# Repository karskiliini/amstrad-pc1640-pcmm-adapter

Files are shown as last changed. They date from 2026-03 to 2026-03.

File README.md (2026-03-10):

# amstrad-pc1640-pcmm-adapter

Video adapter for connecting an Amstrad PC1640 to an Amstrad PC-MM monochrome monitor.

The PC1640 and PC-MM were never designed to work together — the PC-MM was built for the PC1512. This project documents the signal incompatibilities and presents four adapter designs to bridge them.

## The Problem

| Issue | PC1640 output | PC-MM expects |
|---|---|---|
| Connector | DE-9 (9-pin D-sub) | 8-pin DIN |
| Signal polarity | Normal (active-high TTL) | Inverted (active-low TTL) |
| Sync | Separate H-Sync + V-Sync | Composite Sync (combined) |
| Frequency | 21.85 kHz (EGA) / 15.7 kHz (CGA) | 15.75 kHz only |
| Power (14-pin DIN) | Same pinout | Same pinout — **compatible** |

**Solutions:** Run PC1640 in CGA mode (SW8 = OFF) for simplest adapter, or keep EGA mode (SW8 = ON) with additional signal conversion. See options below.

## Documentation

- **[Signal Analysis](docs/signal-analysis.md)** — Full pinouts, signal levels, frequency specs, and compatibility breakdown for both devices

## Adapter Options

### CGA mode (SW8 = OFF) — simpler adapter

| | Option A | Option B | Option C |
|---|---|---|---|
| **Approach** | External adapter | Monitor internal bypass | Passive test cable |
| **ICs needed** | 2 (74HC04 + 74HC86) | 1 (74HC86) | 0 |
| **Monitor mod** | No | Yes | No |
| **Image quality** | Correct | Correct | Inverted (negative) |
| **Cost** | ~15–20€ | ~12–15€ | ~5€ |
| **Difficulty** | Easy | Medium | Very easy |
| **Reversible** | Fully | Partially | Fully |
| **Recommended** | **Yes** | For advanced users | Testing only |

### [Option A: External Adapter](docs/option-a-external-adapter.md) (recommended for CGA mode)

Two ICs on a small PCB handle everything:
- **74HC04** inverts R, G, B, I, and C-Sync to match PC-MM's active-low input
- **74HC86** combines H-Sync + V-Sync into Composite Sync via XOR

No monitor modification needed. Fully reversible.

### [Option B: Monitor Internal Bypass](docs/option-b-monitor-bypass.md)

Bypass the PC-MM's internal TC74HC04 inverter, allowing standard TTL signals to pass through directly. The adapter only needs sync combining (one 74HC86). Smaller and simpler adapter PCB, but requires opening the CRT monitor.

### [Option C: Passive Test Cable](docs/option-c-passive-test.md)

Quick-and-dirty test with just two resistors and direct wiring. Image will be inverted (negative), but confirms that the signal path and frequency are compatible before committing to a PCB design.

---

### EGA mode (SW8 = ON) — preserves full EGA capability

### [Option D: EGA Mode Adapter](docs/option-d-ega-mode.md)

Keep the PC1640 in EGA mode for full 64-color palette capability. This option has two tiers:

**D1: 200-line programs (most DOS games)** — Same adapter as Option A, plus 3 Schottky diodes (or 74HC32 OR gate) to derive the Intensity signal from EGA's three secondary color lines. Works at 15.7 kHz. Cost: ~16–22€.

**D2: 350-line programs (Windows, productivity software)** — PC-MM cannot physically display 21.85 kHz. Requires an external scan rate converter:
- Budget: MCE2VGA + GBS-Control chain (~50–90€)
- Quality: OSSC Pro (~350€)

| | D1 (200-line) | D2 (350-line) |
|---|---|---|
| **Additional HW** | 3 diodes or 1 IC | Scan converter |
| **Programs** | Most DOS games | Windows, SimCity, Flight Sim |
| **H-frequency** | 15.7 kHz (native) | 21.85 kHz → 15.7 kHz (converted) |
| **Cost** | ~16–22€ | ~50–350€ + adapter |
| **Complexity** | Low | High |

## Chosen Design: Option A

Option A (external adapter, no monitor modification) is the selected approach.

### Hardware Files

- [`hardware/netlist.md`](hardware/netlist.md) — Complete point-to-point wiring with ASCII schematic
- [`hardware/bom.csv`](hardware/bom.csv) — Bill of materials with supplier part numbers
- [`hardware/amstrad-pc1640-pcmm-adapter.kicad_pro`](hardware/amstrad-pc1640-pcmm-adapter.kicad_pro) — KiCad project

## Project Status

- [x] Signal analysis and pinout research
- [x] Adapter design (schematic level)
- [x] Netlist and BOM
- [x] KiCad project skeleton
- [ ] KiCad schematic (.kicad_sch)
- [ ] PCB layout (.kicad_pcb)
- [ ] Prototype build and testing
- [ ] Gerber files for manufacturing

## References

- [Amstrad PC1640 Technical Reference Manual](https://www.seasip.info/AmstradXT/1640tech/section1.html)
- [Amstrad PC1512 Technical Reference Manual](https://www.seasip.info/AmstradXT/1512tech/section1.html)
- [PC1640 DIP Switch Settings](https://www.seasip.info/AmstradXT/pc1640dip.html)
- [PC1512 Video Inverter Circuit](https://ctrl-alt-rees.com/2018-09-25-amstrad-pc1512-video-inverter-circuit.html)
- [Amstrad Video Liberator (GitHub)](https://github.com/reeshub/amstrad-pc1512-video-liberator)
- [Necroware MCE Adapter (GitHub)](https://github.com/necroware/mce-adapter)
- [Monotech EGA-Mono-Composite-Converter (GitHub)](https://github.com/monotech/EGA-Mono-Composite-Coverter)

## License

This project is for personal use. Feel free to use and adapt for your own retro computing needs.

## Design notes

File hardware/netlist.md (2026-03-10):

# Netlist — Option A: External Adapter

Complete point-to-point wiring list for the adapter.

## Power

| From | To | Net |
|---|----|-----|
| J3 pin 1 | U1 pin 14, U2 pin 14, R1 (one end) | +5V |
| J3 pin 2 | U1 pin 7, U2 pin 7, J1 pin 1, J2 pin 3, J2 pin 7 | GND |
| C1 | U1 pin 14 → U1 pin 7 | Decoupling U1 |
| C2 | U2 pin 14 → U2 pin 7 | Decoupling U2 |

## Video signals (active-high → inverted via U1)

| PC1640 (J1) | Signal | U1 (74HC04) | PC-MM (J2) |
|---|---|---|---|
| J1 pin 3 | Red (R) | pin 1 → pin 2 (Gate 1) | J2 pin 8 |
| J1 pin 4 | Green (G) | pin 3 → pin 4 (Gate 2) | J2 pin 5 |
| J1 pin 5 | Blue (B) | pin 5 → pin 6 (Gate 3) | J2 pin 6 |
| J1 pin 6 | Intensity (I) | pin 9 → pin 8 (Gate 4) | J2 pin 2 |

## Sync (H+V → XOR → invert → C-Sync)

| PC1640 (J1) | Signal | U2 (74HC86) | U1 (74HC04) | PC-MM (J2) |
|---|---|---|---|---|
| J1 pin 8 | H-Sync | pin 1 (input A) | | |
| J1 pin 9 | V-Sync | pin 2 (input B) | | |
| | C-Sync (raw) | pin 3 (output) → | pin 11 (input) | |
| | C-Sync (inv) | | pin 10 (output) → | J2 pin 1 |

## Black signal

| From | Via | To | Net |
|---|-----|----|-----|
| +5V | R1 (10kΩ) | J2 pin 4 | Black pull-up |

## Unused pins

| IC | Pins | Connection |
|----|---|---|
| U1 | pin 13 (Gate 6 input) | → GND |
| U2 | pin 4, 5 (Gate 2) | → GND |
| U2 | pin 9, 10 (Gate 3) | → GND |
| U2 | pin 12, 13 (Gate 4) | → GND |
| J1 | pin 2 (Sec. Red) | No connection (SW8=OFF grounds this) |
| J1 | pin 7 (Sec. Blue) | No connection |

## Wiring summary

```
                        +5V ─────────────────────────────────┐
                         │                                    │
                    ┌────┴────┐                          ┌────┴────┐
                    │ U1  14  │                          │ U2  14  │
                    │ 74HC04  │                          │ 74HC86  │
J1:3 (R) ─────────→│1      2│─────────→ J2:8 (Red)     │         │
J1:4 (G) ─────────→│3      4│─────────→ J2:5 (Green)   │         │
J1:5 (B) ─────────→│5      6│─────────→ J2:6 (Blue)    │         │
              GND ─→│7       │                     GND ─→│7       │
                    │       8│─────────→ J2:2 (Int)     │         │
J1:6 (I) ─────────→│9       │                          │         │
                    │      10│─────────→ J2:1 (C-Sync)  │         │
              ┌────→│11     │                          │         │
              │     │   12  │                          │         │
        GND ─→│    13│                          J1:8 ──→│1      3│──→ U1:11
              │     └────────┘                  J1:9 ──→│2       │
              │                                         │         │
              └─────────────────────────────────────────│3       │
                                                  GND ─→│4  5   │← GND
                                                  GND ─→│9  10  │← GND
                                                  GND ─→│12 13  │← GND
                                                        └────────┘

J2:4 (Black) ←── R1 (10kΩ) ←── +5V
J2:3, J2:7 ←── GND
J1:1 ←── GND

C1: U1 pin 14 ↔ U1 pin 7 (100nF, close to IC)
C2: U2 pin 14 ↔ U2 pin 7 (100nF, close to IC)
```

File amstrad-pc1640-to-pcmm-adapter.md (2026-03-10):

# Amstrad PC1640 → PC-MM monitoriadapteri

## Löydösten yhteenveto

### PC1640 videolähtö (DE-9 naaras)

| Pin | CGA-tila | EGA-tila |
|-----|---|---|
| 1 | GND | GND |
| 2 | GND | Sec. Red (r) |
| 3 | Red (R) | Primary Red (R) |
| 4 | Green (G) | Primary Green (G)  |
| 5 | Blue (B) | Primary Blue (B) |
| 6 | Intensity (I) | Sec. Green (g) |
| 7 | (ei käytössä) | Sec. Blue (b) |
| 8 | **H-Sync** (+) | **H-Sync** (+) |
| 9 | **V-Sync** (+) | **V-Sync** (-) |

### PC-MM monitorin sisääntulo (8-pin DIN)

| Pin | Signaali |
|-----|---|
| 1 | **Composite Sync** |
| 2 | Intensity |
| 3 | GND |
| 4 | "Black" (harmaasävykontrolli) |
| 5 | Green |
| 6 | Blue |
| 7 | GND |
| 8 | Red |

**Huom:** Kaikki signaalit ovat **invertoituja (active-low)** — PC-MM:n sisällä on TC74HC04-invertteri joka kääntää ne takaisin.

### Kriittiset yhteensopivuusongelmat

1. **Taajuus:** PC-MM toimii 15,75 kHz (CGA). PC1640 EGA-tilassa 21,85 kHz → **ei yhteensopiva**. Ratkaisu: PC1640 asetetaan **CGA-tilaan** (SW8 OFF).
2. **Signaalin polariteetti:** PC1640 lähettää normaalit (active-high) TTL-signaalit. PC-MM odottaa invertoituja (active-low). Monitorin sisäinen invertteri kääntäisi normaalit signaalit väärinpäin → **kuva on negatiivi**.
3. **Synkronointi:** PC1640 lähettää erilliset H-Sync + V-Sync. PC-MM vaatii **Composite Sync**.
4. **Liitin:** DE-9 vs 8-pin DIN.
5. **Virta:** 14-pin DIN -virtaliitin on **sama molemmissa** → suoraan yhteensopiva.

---

## Vaihtoehto A: Ulkoinen adapteri (suositeltu)

Ei vaadi monitorin muokkausta. Kaksi IC:tä hoitavat kaiken.

### Signaalireitti

```
PC1640 (DE-9)           ADAPTERI-PCB                 PC-MM (8-pin DIN)
═════════════           ════════════                 ═════════════════

Pin 3 (R)  ──────────→  74HC04 [inv1] ──────────→  Pin 8 (Red)
Pin 4 (G)  ──────────→  74HC04 [inv2] ──────────→  Pin 5 (Green)
Pin 5 (B)  ──────────→  74HC04 [inv3] ──────────→  Pin 6 (Blue)
Pin 6 (I)  ──────────→  74HC04 [inv4] ──────────→  Pin 2 (Intensity)

Pin 8 (H-Sync) ──→┐
                   ├──→ 74HC86 [XOR] ──→ 74HC04 [inv5] ──→ Pin 1 (C-Sync)
Pin 9 (V-Sync) ──→┘

Pin 1 (GND) ────────────── GND ────────────────→  Pin 3, Pin 7 (GND)
                                                   Pin 4 (Black) ← VCC kautta 10kΩ
```

### IC-kytkennät

**U1: 74HC04 (Hex Inverter)**

```
Pin 14: VCC (+5V)
Pin 7:  GND

Gate 1: Pin 1 (R in)      → Pin 2  (R inv)      → DIN pin 8
Gate 2: Pin 3 (G in)      → Pin 4  (G inv)      → DIN pin 5
Gate 3: Pin 5 (B in)      → Pin 6  (B inv)      → DIN pin 6
Gate 4: Pin 9 (I in)      → Pin 8  (I inv)      → DIN pin 2
Gate 5: Pin 11 (C-Sync)   → Pin 10 (C-Sync inv) → DIN pin 1
Gate 6: Pin 13 → GND (käyttämätön)
```

**U2: 74HC86 (Quad XOR)**

```
Pin 14: VCC (+5V)
Pin 7:  GND

Gate 1: Pin 1 (H-Sync) + Pin 2 (V-Sync) → Pin 3 (C-Sync) → U1 pin 11
Gate 2: Pin 4 → GND, Pin 5 → GND (käyttämätön)
Gate 3: Pin 9 → GND, Pin 10 → GND (käyttämätön)
Gate 4: Pin 12 → GND, Pin 13 → GND (käyttämätön)
```

### Komponenttilista

| #  | Komponentti | Arvo/Tyyppi | Kpl | Hinta (arvio) |
|----|---|---|-----|---|
| U1 | 74HC04 (DIP-14) | Hex inverter | 1  | ~0,50€ |
| U2 | 74HC86 (DIP-14) | Quad XOR | 1  | ~0,50€ |
| C1 | Keraaminen kondensaattori | 100nF | 1  | ~0,05€ |
| C2 | Keraaminen kondensaattori | 100nF | 1  | ~0,05€ |
| R1 | Vastus (Black pull-up) | 10kΩ | 1  | ~0,05€ |
| J1 | DE-9 uros (PCB-mount) | right-angle  | 1  | ~1,50€ |
| J2 | 8-pin DIN naaras (PCB-mount)| panel mount  | 1  | ~2,00€ |
| J3 | USB Micro-B tai 2-pin header| 5V virta | 1  | ~0,50€ |
| | **PCB (5 kpl)** | 2-layer | 1  | ~5€ + posti |
| | | | | **~15–20€** |

### Edut

- Ei monitorin muokkausta
- Vain 2 IC:tä, yksinkertainen kytkentä
- Helppo rakentaa myös protolevylle
- Täysin palautettavissa (ei pysyviä muutoksia)

### Haitat

- Tarvitsee erillisen 5V-virransyötön (USB-laturi)
- Hieman isompi PCB kuin vaihtoehto B

---

## Vaihtoehto B: Monitorin sisäisen invertterin ohitus

Avataan PC-MM ja ohitetaan TC74HC04-invertteri. Tämän jälkeen adapteri tarvitsee vain sync-yhdistämisen.

### Monitorin muokkaus

1. Avaa PC-MM:n kotelo
2. Paikanna TC74HC04 (hex inverter) piirilevyltä
3. Juota ohuet langat jokaisen portin sisääntulosta suoraan ulostuloon (bypass)
4. TAI poista IC kannastaan ja korvaa se langoituksella

### Signaalireitti (muokattu monitori)

```
PC1640 (DE-9)           ADAPTERI-PCB                 PC-MM (8-pin DIN)
═════════════           ════════════                 ═════════════════

Pin 3 (R)  ──────────────────────────────────────→  Pin 8 (Red)
Pin 4 (G)  ──────────────────────────────────────→  Pin 5 (Green)
Pin 5 (B)  ──────────────────────────────────────→  Pin 6 (Blue)
Pin 6 (I)  ──────────────────────────────────────→  Pin 2 (Intensity)

Pin 8 (H-Sync) ──→┐
                   ├──→ 74HC86 [XOR] ──────────→  Pin 1 (C-Sync)
Pin 9 (V-Sync) ──→┘

Pin 1 (GND) ────────────── GND ────────────────→  Pin 3, Pin 7 (GND)
                                                   Pin 4 (Black) ← VCC kautta 10kΩ
```

### Komponenttilista

| #  | Komponentti | Arvo/Tyyppi | Kpl | Hinta (arvio) |
|----|---|---|-----|---|
| U1 | 74HC86 (DIP-14) | Quad XOR | 1  | ~0,50€ |
| C1 | Keraaminen kondensaattori | 100nF | 1  | ~0,05€ |
| R1 | Vastus (Black pull-up) | 10kΩ | 1  | ~0,05€ |
| J1 | DE-9 uros (PCB-mount) | right-angle  | 1  | ~1,50€ |
| J2 | 8-pin DIN naaras (PCB-mount)| panel mount  | 1  | ~2,00€ |
| J3 | USB Micro-B tai 2-pin header| 5V virta | 1  | ~0,50€ |
| | **PCB (5 kpl)** | 2-layer | 1  | ~5€ + posti |
| | | | | **~12–15€** |

### Edut

- Yksinkertaisempi adapteri (vain 1 IC)
- Suorat signaaliyhteydet R/G/B/I → ei viivettä

### Haitat

- **Vaatii monitorin avaamisen ja muokkauksen**
- PC-MM on keräilykohde — muokkaus voi laskea arvoa
- Jos invertteri ohitetaan väärin, monitori ei toimi PC1512:n kanssa enää
- CRT-monitorin sisällä on vaarallisia jännitteitä (huolellinen purkaus!)

---

## Vaihtoehto C: Passiivinen adapteri ilman IC:tä (testaustarkoituksiin)

Jos haluat kokeilla nopeasti ilman IC-hankintoja ja sinulla on protolevyä:

### Periaate

- Kytke R/G/B/I suoraan (ilman inversiota)
- Sync: yhdistä H-Sync ja V-Sync **vastusverkon** kautta (ei XOR, mutta voi toimia)
- Hyväksy että kuva on negatiivi (valkoinen teksti → musta teksti, musta tausta → valkoinen tausta)

### Kytkentä

```
PC1640 Pin 8 (H-Sync) ──── 1kΩ ──→┐
                                    ├──→ DIN Pin 1 (C-Sync)
PC1640 Pin 9 (V-Sync) ──── 1kΩ ──→┘
```

### Arvio

- **Toimii ehkä** — kuva on käänteinen mutta näet jotain
- Vastusverkon sync ei ole tarkka, kuva voi vääristyä reunoilta
- Hyvä **ensimmäiseksi testiksi** ennen PCB-suunnittelua

---

## Vertailutaulukko

| Ominaisuus | A: Ulkoinen adapteri | B: Monitorin muokkaus | C: Passiivinen testi |
|---|---|---|---|
| IC:tä tarvitaan | 2 (74HC04 + 74HC86) | 1 (74HC86) | 0 |
| Monitorin muokkaus | Ei | Kyllä | Ei |
| Kuvan laatu | Oikea | Oikea | Negatiivi/epätarkka  |
| Hinta | ~15–20€ | ~12–15€ | ~5€ |
| Vaikeus | Helppo | Keskitaso | Erittäin helppo |
| Palautettavuus | Täysi | Osittainen | Täysi |
| Sopii tuotantokäyttöön | Kyllä | Kyllä | Ei |

---

## PC1640 DIP-kytkinasetukset CGA-tilalle

PC1640:n emolevyllä:
- **SW8 = OFF** → CGA/MDA-tila (pin 2 maadoitettu)
- Muut kytkimet CGA-näyttötilaan sopiviksi

---

## Testaussuunnitelma

1. Mittaa adapterilta tulevat signaalit oskilloskoopilla/logiikka-analysaattorilla
2. Tarkista C-Sync: XOR(H-Sync, V-Sync) tuottaa oikean aaltomuodon
3. Tarkista inversio: signaalien polariteetti on käänteinen suhteessa sisääntuloon
4. Liitä PC-MM: jos kuva on negatiivi → inversio puuttuu/väärin. Jos rullaa → sync väärin
5. "Black"-pin (DIN pin 4): kokeile VCC / GND / irti — katso vaikutus kuvaan

---

## Avoimet kysymykset

- **"Black"-pinin (DIN pin 4) tarkka toiminta** — vaatii PC-MM:n huoltomanuaalin tarkemman tutkimisen
- **Sync-polariteetti** — XOR + inversio pitäisi tuottaa oikean tuloksen, mutta vaatii testauksen
- **PC1640 CGA-yhteensopivuus** — Paradise PEGA1A -piiri tukee CGA-tilaa, mutta ohjelmistoyhteensopivuus vaihtelee

---

## Lähteet

- [Amstrad PC1640 Technical Reference Manual (seasip.info)](https://www.seasip.info/AmstradXT/1640tech/section1.html)
- [Amstrad PC1512 Technical Reference Manual (seasip.info)](https://www.seasip.info/AmstradXT/1512tech/section1.html)
- [PC1640 DIP Switch Settings (seasip.info)](https://www.seasip.info/AmstradXT/pc1640dip.html)
- [Amstrad PC1640 Revival (RetroNerd)](https://retronerd.co.uk/amstrad-pc1640-revival/)
- [PC1512 Video Inverter Circuit (ctrl-alt-rees.com)](https://ctrl-alt-rees.com/2018-09-25-amstrad-pc1512-video-inverter-circuit.html)
- [PC1512 External PSU (ctrl-alt-rees.com)](https://ctrl-alt-rees.com/2018-09-10-amstrad-pc1512-building-an-external-power-supply.html)
- [Amstrad Video Liberator (GitHub)](https://github.com/reeshub/amstrad-pc1512-video-liberator)
- [Monotech EGA-Mono-Composite-Converter (GitHub)](https://github.com/monotech/EGA-Mono-Composite-Coverter)
- [Necroware MCE Adapter (GitHub)](https://github.com/necroware/mce-adapter)
- [GGLabs CGA2RGBv2](https://gglabs.us/node/2063)
- [Amstrad PC1640 Service Manual (PDF)](https://www.minuszerodegrees.net/manuals/Amstrad/Amstrad_PC1640_PC-MD_PC-CD_PC-ECD_Service_Manual_300dpi_Agujereado.pdf)
- [Amstrad PC1512 PC-MM Service Manual (Internet Archive)](https://archive.org/details/amstrad-pc1512-pc-mm-pc-cm-service-manual)
- [IBM MDA/CGA/EGA Pinouts (minuszerodegrees.net)](https://www.minuszerodegrees.net/mda_cga_ega/mda_cga_ega.htm)

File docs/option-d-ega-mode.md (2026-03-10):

# Vaihtoehto D: PC1640 EGA-tilassa

PC1640 pidetään EGA-tilassa (SW8 = ON). Tämä tuo kaksi erillistä haastetta riippuen ajettavasta ohjelmistosta.

## Taustaa: EGA-tilan kaksi toimintataajuutta

EGA-kortti (Paradise PEGA1A) vaihtaa automaattisesti kahden taajuuden välillä:

| Ohjelmatila | Resoluutio | H-taajuus  | V-Sync polariteetti | PC-MM yhteensopiva? |
|---|---|---|---|---|
| CGA-yhteensopiva | 320×200 / 640×200 | **15,7 kHz** | positiivinen (+) | **Kyllä** |
| Natiivi EGA | 640×350 | **21,85 kHz** | negatiivinen (-) | **Ei** |

**Suurin osa EGA-peleistä** käyttää 200-rivin tiloja (320×200, mode 0Dh/0Eh) jotka toimivat 15,7 kHz:llä. Vain osa ohjelmista vaatii 350-rivin tilaa.

---

## D1: EGA-tila, 200-rivin ohjelmat (15,7 kHz)

Toimii samalla adapterilla kuin vaihtoehto A, mutta tarvitsee **EGA 6-bit → CGA 4-bit RGBI** -signaalimappauksen.

### Ongelma: 6 signaalia → 4 signaalia

EGA-tilassa (SW8 = ON) PC1640 lähettää 6 digitaalista signaalia:

| Pin | Signaali | Rooli |
|-----|---|---|
| 2 | Sec. Red (r) | 1/3 punainen |
| 3 | Primary Red (R) | 2/3 punainen |
| 4 | Primary Green (G) | 2/3 vihreä |
| 5 | Primary Blue (B) | 2/3 sininen |
| 6 | Sec. Green (g) | 1/3 vihreä |
| 7 | Sec. Blue (b) | 1/3 sininen |

PC-MM odottaa 4 signaalia: **R, G, B, I** (Intensity).

### Ratkaisu: Intensity = OR(r, g, b)

CGA-yhteensopivissa ohjelmissa EGA-paletti mappaa värit niin, että intensiteetti näkyy sekundaarisignaaleissa. Yksinkertaisin konversio:

```
R = Pin 3 (Primary Red)
G = Pin 4 (Primary Green)
B = Pin 5 (Primary Blue)
I = OR(Pin 2, Pin 6, Pin 7)  ← yhdistetään kaikki sekundaarisignaalit
```

**Huomio:** Tämä mappaus ei ole täydellinen. CGA-väri 6 (ruskea, EGA-paletti 010100) tulkitaan väärin: sekundaari-vihreä=1 tuottaa Intensity=1, vaikka CGA:ssa ruskean intensiteetti on 0. **Monokroomonitorilla** tämä näkyy vain pienenä kirkkauserona yhdessä värissä — käytännössä merkityksetöntä.

### Signaalireitti

```
PC1640 (DE-9, EGA)      ADAPTERI-PCB                    PC-MM (8-pin DIN)
══════════════════      ════════════                    ═════════════════

Pin 3 (R)  ──────────→  74HC04 [inv] ──────────────→  Pin 8 (Red)
Pin 4 (G)  ──────────→  74HC04 [inv] ──────────────→  Pin 5 (Green)
Pin 5 (B)  ──────────→  74HC04 [inv] ──────────────→  Pin 6 (Blue)

Pin 2 (r)  ──→ D1 ──→┐
Pin 6 (g)  ──→ D2 ──→├──→ 74HC04 [inv] ───────────→  Pin 2 (Intensity)
Pin 7 (b)  ──→ D3 ──→┘
                (diode-OR)

Pin 8 (H-Sync) ──→┐
                   ├──→ 74HC86 [XOR] → 74HC04 [inv] → Pin 1 (C-Sync)
Pin 9 (V-Sync) ──→┘

Pin 1 (GND) ────────────── GND ───────────────────→  Pin 3, Pin 7 (GND)
                                                      Pin 4 (Black) ← VCC kautta 10kΩ
```

### Diode-OR toteutus

Kolme Schottky-diodia (esim. BAT85 tai 1N5817) yhdistävät sekundaarisignaalit:

```
Pin 2 (r) ──── ▷|──→┐
Pin 6 (g) ──── ▷|──→├──→ I (→ 74HC04 inverteriin)
Pin 7 (b) ──── ▷|──→┘
                     │
                    10kΩ → GND (pull-down)
```

Schottky-diodin jännitehäviö ~0,3V. TTL HIGH ≥ 2,4V → 2,4V - 0,3V = 2,1V → riittävä 74HC04:lle (kynnys ~1,5V).

### Komponenttilista (BOM)

| Ref | Komponentti | Arvo/Tyyppi | Kpl | Hinta  |
|-----|---|---|-----|---|
| U1  | 74HC04 hex inverter | DIP-14 | 1 | ~0,50€ |
| U2  | 74HC86 quad XOR | DIP-14 | 1 | ~0,50€ |
| D1–D3 | Schottky-diodi | BAT85 / 1N5817 | 3 | ~0,30€ |
| C1  | Keraaminen kondensaattori | 100nF | 1 | ~0,05€ |
| C2  | Keraaminen kondensaattori | 100nF | 1 | ~0,05€ |
| R1  | Vastus (Black pull-up) | 10kΩ 1/4W | 1 | ~0,05€ |
| R2  | Vastus (diode-OR pull-down) | 10kΩ 1/4W | 1 | ~0,05€ |
| J1  | DE-9 uros, PCB-mount | right-angle | 1 | ~1,50€ |
| J2  | 8-pin DIN naaras | panel mount | 1 | ~2,00€ |
| J3  | USB Micro-B / 2-pin header | 5V virta | 1 | ~0,50€ |
| | **PCB 2-layer (5 kpl)** | FR4 | 1 | ~5€ |
| | | | | ~16–22€|

### Vaihtoehto: 74HC32 diodien sijaan

Jos haluat täysin digitaalisen ratkaisun, korvaa Schottky-diodit 74HC32:lla (quad OR gate):

```
Gate 1: Pin 2 (r) OR Pin 6 (g) → väliaikainen
Gate 2: väliaikainen OR Pin 7 (b) → Intensity
Gate 3–4: käyttämättömät (sisääntulot → GND)
```

Tämä lisää yhden IC:n mutta eliminoi diodien jännitehäviön.

---

## D2: Natiivi EGA 350-rivin tila (21,85 kHz) — vaatii scan-konvertterin

PC-MM **ei fyysisesti pysty** näyttämään 21,85 kHz signaalia. CRT:n vaakataajuuspiiri on suunniteltu vain 15,75 kHz:lle. Tarvitaan ulkoinen **scan rate -konvertteri** joka:

1. Vastaanottaa 21,85 kHz EGA-signaalin
2. Puskuroi kuvan muistiin (frame buffer)
3. Tulostaa sen uudelleen 15,75 kHz:llä

### Vaihtoehdot scan-konvertteriksi

#### OSSC Pro (~350€) — paras yksittäinen ratkaisu

```
PC1640 (DE-9 TTL) → vastusverkko (TTL→analog) → OSSC Pro → analog RGB 15kHz → adapteri → PC-MM
```

- Hyväksyy ~24 kHz tulotaajuuden (preset 350–400p lähteille)
- Voi tuottaa 240p / 15 kHz ulostuloa
- Tarvitsee TTL-to-analog konversion ennen OSSC:tä (yksinkertainen vastusverkko)
- Tarvitsee analog-to-TTL konversion OSSC:n jälkeen PC-MM:lle
- **Ongelmia:** kallein vaihtoehto, kaksi ylimääräistä konversiota, ei testattu spesifisesti EGA 21,85 kHz:llä

#### MCE2VGA + GBS-Control ketju (~50–90€) — budjettitasolla paras

```
PC1640 (DE-9 TTL) → MCE2VGA (EGA→VGA 31kHz) → GBS-Control (VGA→240p 15kHz) → adapteri → PC-MM
```

- **MCE2VGA** (~25–50€): FPGA-pohjainen, hyväksyy EGA TTL suoraan, tuottaa VGA-signaalin
- **GBS-8200 + GBS-Control** (~15–25€ + ESP8266 ~5€): vastaanottaa VGA:n, tuottaa 240p / 15 kHz
- Molemmat laitteet ovat hyvin testattuja erikseen
- **Ongelmia:** kaksi erillistä laitetta, lisäkaapelointi, mahdollinen viive (~1 frame)

#### Dual GBS-Control ketju (~50–80€) — epävarma

```
PC1640 → vastusverkko → GBS-Control #1 (21kHz→31kHz) → GBS-Control #2 (31kHz→15kHz) → adapteri → PC-MM
```

- Halvempi kuin MCE2VGA-ketju
- **Suuri riski:** GBS-8200 ei välttämättä lukitu 21,85 kHz taajuuteen (stock-firmware tukee 15/24/31 kHz)
- GBS-Control firmware laajentaa lukitusaluetta, mutta 21,85 kHz on "kuollut alue"
- **Ei suositella** ilman ennakkotestausta

### Hintavertailu scan-konvertterivaihtoehdoista

| Ratkaisu | Hinta | Luotettavuus | Laitteiden määrä |
|---|---|---|---|
| OSSC Pro | ~350€ | Korkea (mutta ei testattu EGA:lla) | 1 + adapterit |
| MCE2VGA + GBS-Control | ~50–90€ | Hyvä (testatut komponentit) | 2 + adapteri |
| Dual GBS-Control | ~50–80€ | Epävarma (21 kHz lukitus?) | 2 + adapteri |
| Custom FPGA | ~25–50€ + työ | Riippuu toteutuksesta | 1 + adapteri |

---

## Ohjelmistoyhteensopivuus: tarvitsetko oikeasti 350-rivin tilaa?

Suurin osa DOS-peleistä käyttää **200-rivin tiloja** jotka toimivat 15,7 kHz:llä:

### 200-rivin EGA-pelejä (toimivat suoraan D1-adapterilla)

- King's Quest I–IV
- Space Quest I–III
- Leisure Suit Larry 1–2
- Maniac Mansion
- Lemmings
- Prince of Persia
- Commander Keen
- Wolfenstein 3D
- Doom (fallback)
- Monkey Island 1–2
- Suurin osa Sierra, LucasArts, Apogee -peleistä

### 350-rivin EGA-ohjelmia (vaativat scan-konvertterin)

- SimCity (1989)
- Microsoft Flight Simulator 3.0 / 5.0
- Windows 3.x EGA-tilassa
- Useimmat tuottavuusohjelmat (Word, Excel, Lotus 1-2-3)
- Osa strategiapeleistä (Gary Grigsby -sarjat)

**Jos käyttötarkoituksesi on pääasiassa DOS-pelejä, D1-ratkaisu (200-rivin tila) riittää todennäköisesti.**

---

## Suositus

| Käyttötarkoitus | Suositeltu ratkaisu | Hinta |
|---|---|---|
| DOS-pelit (suurin osa) | **D1**: adapteri + diode-OR | ~16–22€ |
| 350-rivin ohjelmat (budjetti) | **D2**: MCE2VGA + GBS-Control | ~50–90€ + adapteri |
| 350-rivin ohjelmat (laatu) | **D2**: OSSC Pro | ~350€ + adapterit |
| Kaikki tilat ilman rajoituksia | Hanki EGA-monitori tai multisync | vaihtelee |

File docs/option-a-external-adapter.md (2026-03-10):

# Vaihtoehto A: Ulkoinen adapteri (suositeltu)

Ei vaadi monitorin muokkausta. Kaksi IC:tä hoitavat signaalin invertoinnin ja sync-yhdistämisen.

## Toimintaperiaate

1. **74HC86 (XOR)** yhdistää erilliset H-Sync + V-Sync → Composite Sync
2. **74HC04 (invertteri)** kääntää R, G, B, I ja C-Sync signaalien polariteetin active-low -muotoon, jota PC-MM odottaa

## Signaalireitti

```
PC1640 (DE-9)           ADAPTERI-PCB                 PC-MM (8-pin DIN)
═════════════           ════════════                 ═════════════════

Pin 3 (R)  ──────────→  74HC04 [inv1] ──────────→  Pin 8 (Red)
Pin 4 (G)  ──────────→  74HC04 [inv2] ──────────→  Pin 5 (Green)
Pin 5 (B)  ──────────→  74HC04 [inv3] ──────────→  Pin 6 (Blue)
Pin 6 (I)  ──────────→  74HC04 [inv4] ──────────→  Pin 2 (Intensity)

Pin 8 (H-Sync) ──→┐
                   ├──→ 74HC86 [XOR] ──→ 74HC04 [inv5] ──→ Pin 1 (C-Sync)
Pin 9 (V-Sync) ──→┘

Pin 1 (GND) ────────────── GND ────────────────→  Pin 3, Pin 7 (GND)
                                                   Pin 4 (Black) ← VCC kautta 10kΩ
```

## IC-kytkennät

### U1: 74HC04 (Hex Inverter, DIP-14)

```
        ┌──── U1: 74HC04 ────┐
  R in →│ 1  [INV1]  14 │← VCC (+5V)
 R out ←│ 2          13 │← käyttämätön (→ GND)
  G in →│ 3  [INV2]  12 │→ käyttämätön
 G out ←│ 4          11 │← C-Sync in (U2 pin 3:sta)
  B in →│ 5  [INV3]  10 │→ C-Sync inv out → DIN pin 1
 B out ←│ 6           9 │← I in
   GND →│ 7           8 │→ I inv out → DIN pin 2
        └────────────────┘

Gate 1: Pin 1 (R in)      → Pin 2  (R inv)      → DIN pin 8
Gate 2: Pin 3 (G in)      → Pin 4  (G inv)      → DIN pin 5
Gate 3: Pin 5 (B in)      → Pin 6  (B inv)      → DIN pin 6
Gate 4: Pin 9 (I in)      → Pin 8  (I inv)      → DIN pin 2
Gate 5: Pin 11 (C-Sync)   → Pin 10 (C-Sync inv) → DIN pin 1
Gate 6: Pin 13 → GND (käyttämätön)
```

### U2: 74HC86 (Quad XOR, DIP-14)

```
          ┌──── U2: 74HC86 ────┐
 H-Sync →│ 1  [XOR1]  14 │← VCC (+5V)
 V-Sync →│ 2          13 │← GND (käyttämätön)
C-Sync  ←│ 3          12 │← GND (käyttämätön)
    GND →│ 4  [XOR2]  11 │→ (käyttämätön)
    GND →│ 5          10 │← GND (käyttämätön)
        →│ 6           9 │← GND (käyttämätön)
    GND →│ 7           8 │→ (käyttämätön)
          └────────────────┘

Gate 1: Pin 1 (H-Sync) + Pin 2 (V-Sync) → Pin 3 (C-Sync) → U1 pin 11
Gate 2–4: käyttämättömät, sisääntulot GND:hen
```

## Komponenttilista (BOM)

| Ref | Komponentti | Arvo/Tyyppi  | Kpl | Footprint | Hinta  |
|-----|---|---|-----|---|---|
| U1  | 74HC04 hex inverter | DIP-14 | 1 | DIP-14 | ~0,50€ |
| U2  | 74HC86 quad XOR | DIP-14 | 1 | DIP-14 | ~0,50€ |
| C1  | Keraaminen kondensaattori | 100nF | 1 | C_Disc_5mm  | ~0,05€ |
| C2  | Keraaminen kondensaattori | 100nF | 1 | C_Disc_5mm  | ~0,05€ |
| R1  | Vastus (Black pull-up) | 10kΩ 1/4W | 1 | Axial_7.6mm | ~0,05€ |
| J1  | DE-9 uros, PCB-mount | right-angle  | 1 | DE-9_Male | ~1,50€ |
| J2  | 8-pin DIN naaras, PCB-mount | panel mount  | 1 | DIN-8 | ~2,00€ |
| J3  | USB Micro-B tai 2-pin header  | 5V virta | 1 | — | ~0,50€ |
| | **PCB 2-layer (5 kpl)** | FR4 | 1 | ~50×35mm | ~5€ |
| | | | | **Yhteensä**| ~15–20€|

## PCB-layout suuntaviiva

```
┌─────────────────────────────────────────┐
│                                         │
│  [J1: DE-9]    [U1]  [U2]    [J2: DIN] │
│   uros         HC04  HC86    naaras     │
│               [C1]  [C2]               │
│                [R1]                      │
│                        [J3: +5V/GND]    │
│                                         │
└─────────────────────────────────────────┘
Koko: ~50 × 35 mm, 2-layer, through-hole
```

## Virransyöttö

IC:t tarvitsevat +5V, yhteensä < 30 mA. Vaihtoehdot:

1. **USB Micro-B / USB-C PCB:llä** — mikä tahansa puhelinlaturi käy (suositeltu)
2. **2-pin header** + erillinen 5V-lähde
3. **Haaroitus 14-pin DIN -virtakaapelista** — siistimpi mutta vaatii lisäkaapelin

## PC1640 asetukset

DIP-kytkin emolevyllä:
- **SW8 = OFF** → CGA-tila (pin 2 maadoitettu)
- Tarkista muut kytkimet CGA-yhteensopivuudelle

## Edut

- Ei monitorin muokkausta — täysin palautettavissa
- Vain 2 halpaa IC:tä, yksinkertainen kytkentä
- Helppo rakentaa myös protolevylle (perfboard)
- Monitori toimii edelleen PC1512:n kanssa ilman adapteria

## Haitat

- Tarvitsee erillisen 5V-virransyötön
- Hieman isompi kuin vaihtoehto B

## Rakentaminen protolevylle (nopea versio)

Jos haluat testata ennen PCB-tilausta:

1. Kiinnitä 74HC04 ja 74HC86 protolevylle
2. Kytke VCC (+5V) ja GND molempiin IC:ihin
3. Lisää 100nF kondensaattorit VCC/GND-pinnien viereen
4. Juota signaalijohtimet DE-9-liittimestä IC:ille ja IC:iltä DIN-liittimeen
5. Käytä USB-kaapelia virransyöttöön (leikkaa vanha USB-kaapeli, käytä +5V ja GND)

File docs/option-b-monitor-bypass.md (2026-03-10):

# Vaihtoehto B: Monitorin sisäisen invertterin ohitus

Avataan PC-MM ja ohitetaan sen sisäinen TC74HC04-invertteri. Tämän jälkeen adapteri tarvitsee vain sync-yhdistämisen.

## Toimintaperiaate

PC-MM:n sisällä oleva TC74HC04 invertoi kaikki signaalit, koska PC1512 lähettää ne käänteisesti. Kun invertteri ohitetaan, monitori hyväksyy normaalit (active-high) signaalit suoraan PC1640:sta.

## Monitorin muokkaus

> **VAROITUS:** CRT-monitorin sisällä on hengenvaarallisia jännitteitä (jopa tuhansia voltteja). Anna monitorin olla irti verkkovirrasta vähintään 24 tuntia ja pura CRT:n jännitys ennen työskentelyä.

### Vaiheet

1. Irrota monitori verkkovirrasta ja anna purkautua **vähintään 24h**
2. Avaa PC-MM:n kotelo (ruuvit takapaneelissa)
3. Paikanna **TC74HC04** (hex inverter) piirilevyltä — se on lähellä videoliittimen sisääntulopistettä
4. Tee yksi seuraavista:

**Vaihtoehto B1: IC:n korvaaminen langoituksella**
- Irrota TC74HC04 kannastaan (jos IC-kanta) tai irrojuota
- Juota ohuet langat jokaisen portin sisääntulosta suoraan ulostuloon:
  - Pin 1 → Pin 2
  - Pin 3 → Pin 4
  - Pin 5 → Pin 6
  - Pin 9 → Pin 8
  - Pin 11 → Pin 10
  - Pin 13 → Pin 12
- Jätä VCC (pin 14) ja GND (pin 7) kytkettyinä

**Vaihtoehto B2: Piggyback-IC** (palautettava)
- Juota 74HC04 **päälle** uusi IC jonka sisääntulopinnit on kytketty suoraan ulostulopinneihin
- Tämä kumoaa invertoinnin (kaksi peräkkäistä invertteriä = läpikulku)
- Helpompi peruuttaa: poista vain päällimmäinen IC

## Signaalireitti (muokattu monitori)

```
PC1640 (DE-9)           ADAPTERI-PCB                 PC-MM (8-pin DIN)
═════════════           ════════════                 ═════════════════

Pin 3 (R)  ──────────── suora ─────────────────→  Pin 8 (Red)
Pin 4 (G)  ──────────── suora ─────────────────→  Pin 5 (Green)
Pin 5 (B)  ──────────── suora ─────────────────→  Pin 6 (Blue)
Pin 6 (I)  ──────────── suora ─────────────────→  Pin 2 (Intensity)

Pin 8 (H-Sync) ──→┐
                   ├──→ 74HC86 [XOR] ──────────→  Pin 1 (C-Sync)
Pin 9 (V-Sync) ──→┘

Pin 1 (GND) ────────────── GND ────────────────→  Pin 3, Pin 7 (GND)
                                                   Pin 4 (Black) ← VCC kautta 10kΩ
```

## IC-kytkennät

### U1: 74HC86 (Quad XOR, DIP-14)

```
Gate 1: Pin 1 (H-Sync) + Pin 2 (V-Sync) → Pin 3 (C-Sync) → DIN pin 1
Gate 2–4: käyttämättömät, sisääntulot GND:hen

Pin 14: VCC (+5V)
Pin 7:  GND
```

## Komponenttilista (BOM)

| Ref | Komponentti | Arvo/Tyyppi  | Kpl | Hinta  |
|-----|---|---|-----|---|
| U1  | 74HC86 quad XOR | DIP-14 | 1 | ~0,50€ |
| C1  | Keraaminen kondensaattori | 100nF | 1 | ~0,05€ |
| R1  | Vastus (Black pull-up) | 10kΩ 1/4W | 1 | ~0,05€ |
| J1  | DE-9 uros, PCB-mount | right-angle  | 1 | ~1,50€ |
| J2  | 8-pin DIN naaras, PCB-mount | panel mount  | 1 | ~2,00€ |
| J3  | USB Micro-B tai 2-pin header  | 5V virta | 1 | ~0,50€ |
| | **PCB 2-layer (5 kpl)** | FR4 | 1 | ~5€ |
| | | | | ~12–15€|

## PCB-layout suuntaviiva

```
┌──────────────────────────────────┐
│                                  │
│  [J1: DE-9]   [U1]   [J2: DIN]  │
│   uros        HC86   naaras     │
│              [C1][R1]            │
│                   [J3: +5V/GND]  │
│                                  │
└──────────────────────────────────┘
Koko: ~40 × 25 mm, 2-layer, through-hole
```

## Edut

- Yksinkertaisempi adapteri (vain 1 IC)
- Suorat signaaliyhteydet R/G/B/I — ei ylimääräistä viivettä
- Pienempi PCB

## Haitat

- **Vaatii monitorin avaamisen** — CRT-jännitteet ovat vaarallisia
- PC-MM on keräilykohde — muokkaus voi laskea arvoa
- Jos invertteri ohitetaan, monitori **ei toimi enää PC1512:n kanssa** (ellei käytetä piggyback-menetelmää)
- Piggyback-menetelmä mahdollistaa palautuksen, mutta on kömpelömpi

## Palautettavuus

| Menetelmä | Palautettavuus |
|---|---|
| IC:n irrotus + langat | Vaikea — vaatii uuden TC74HC04:n juottamisen |
| Piggyback-IC | Helppo — poista päällimmäinen IC |
| IC-kanta + irrotus  | Helppo — aseta alkuperäinen IC takaisin kantaan |

**Suositus:** Jos monitorissa on IC-kanta, irrota alkuperäinen IC ja korvaa se langoitetulla kannalla. Jos IC on juotettu suoraan, käytä piggyback-menetelmää.

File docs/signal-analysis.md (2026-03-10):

# Signaalianalyysi: PC1640 ↔ PC-MM yhteensopivuus

## PC1640 videolähtö (DE-9 naaras, takapaneeli)

PC1640 käyttää standardia 9-pin DE-9 -videoliitintä. Signaalikartta riippuu käyttötilasta:

| Pin | CGA-tila | EGA-tila | MDA-tila |
|-----|---|---|---|
| 1 | GND | GND | GND |
| 2 | GND | Sec. Red (r) | GND |
| 3 | Red (R) | Primary Red (R) | (ei käytössä) |
| 4 | Green (G) | Primary Green (G)  | (ei käytössä) |
| 5 | Blue (B) | Primary Blue (B) | (ei käytössä) |
| 6 | Intensity (I) | Sec. Green (g) | Intensity (I) |
| 7 | (ei käytössä) | Sec. Blue (b) | Mono Video (V) |
| 8 | **H-Sync** (+) | **H-Sync** (+) | **H-Sync** (+) |
| 9 | **V-Sync** (+) | **V-Sync** (-) | **V-Sync** (-) |

**Signaalitasot:** Kaikki digitaalisia TTL-tasoja (+5V HIGH / 0V LOW).

**DIP-kytkin SW8:** ON = EGA (pin 2 = Sec. Red), OFF = CGA/MDA (pin 2 = GND).

### Synkronointitaajuudet tilasta riippuen

| Tila | H-Sync | V-Sync | H-polariteetti | V-polariteetti |
|---|---|---|---|---|
| CGA | 15,7 kHz  | 60 Hz | positiivinen | positiivinen |
| EGA | 21,85 kHz | 60 Hz | positiivinen | negatiivinen |
| MDA | 18,43 kHz | 50 Hz | positiivinen | negatiivinen |

---

## PC-MM monitorin sisääntulo (8-pin DIN)

PC-MM liittyy PC1512:een kahdella kaapelilla: video (8-pin DIN) ja virta (14-pin DIN).

### Video-liitin (8-pin DIN)

| Pin | Signaali | Johdon väri (tyypillinen) |
|-----|---|---|
| 1 | **Composite Sync** | valkoinen |
| 2 | Intensity | keltainen |
| 3 | GND | musta |
| 4 | "Black" (harmaasävykontrolli) | harmaa |
| 5 | Green | vihreä |
| 6 | Blue | sininen |
| 7 | GND | musta |
| 8 | Red | punainen |

### Signaalin erikoispiirteet

- **Kaikki signaalit ovat invertoituja (active-low)**. PC1512 lähettää käänteiset TTL-signaalit.
- Monitorin sisällä on **TC74HC04 hex-invertteri** joka kääntää signaalit takaisin oikein.
- Harmaasävypainokertoimet monitorin sisällä: **R=2, G=4, B=1, I=8** → 16 harmaasävyä.
- Sisääntulossa 75Ω pull-down -vastukset ja 100Ω sarjavastukset.

### Toimintataajuudet

| Parametri | Arvo |
|---|---|
| H-taajuus | 15,75 kHz |
| V-taajuus | 60 Hz |
| Näyttötila | 200 juovaa progressiivinen |

---

## Virtaliitin (14-pin DIN, yhteinen molemmille)

PC-MM:n sisäinen virtalähde syöttää virran tietokoneelle tämän liittimen kautta. **Sama pinout molemmissa koneissa.**

| Pin | Signaali |
|-----|---|
| 1 | N/C |
| 2 | GND |
| 3 | +5V DC |
| 4 | GND |
| 5 | +5V DC |
| 6 | N/C |
| 7 | N/C |
| 8 | GND |
| 9 | -12V DC |
| 10  | GND |
| 11  | +12V DC |
| 12  | GND |
| 13  | -5V DC |
| 14  | N/C |

**Huom:** +5V on kahdella pinnillä (3, 5) virtankestävyyden vuoksi. Monitorin PSU: +5V max 7A, +12V max 4,9A.

---

## Yhteensopivuusongelmat

### 1. Taajuus — KRIITTINEN

PC-MM käsittelee **vain 15,75 kHz** horisontaalista taajuutta. PC1640:n EGA-tila tuottaa 21,85 kHz → **monitori ei synkronoidu**.

**Ratkaisu:** PC1640 asetetaan CGA-tilaan (SW8 = OFF), jolloin H-Sync = 15,7 kHz.

### 2. Signaalin polariteetti — KRIITTINEN

| Laite | Signaalilogiikka |
|---|---|
| PC1640  | Normaali (active-high TTL) |
| PC1512  | Invertoitu (active-low TTL) |
| PC-MM | Odottaa invertoitua → sisäinen TC74HC04 kääntää takaisin |

Jos PC1640:n normaalit signaalit syötetään PC-MM:ään, sisäinen invertteri kääntää ne → **kuva on negatiivi**.

### 3. Synkronointi — KRIITTINEN

| Laite | Sync-tyyppi |
|---|---|
| PC1640  | Erilliset H-Sync (pin 8) + V-Sync (pin 9) |
| PC-MM | Composite Sync (yhdistetty, pin 1) |

Tarvitaan XOR-piiri yhdistämään H-Sync + V-Sync → C-Sync.

### 4. Liitin — fyysinen ero

| Laite | Liitin |
|---|---|
| PC1640  | DE-9 (9-pin D-sub) naaras |
| PC-MM | 8-pin DIN uros (kaapelissa) |

### 5. Virta — YHTEENSOPIVA

14-pin DIN -virtaliitin on identtinen. PC-MM:n virtakaapeli kytkeytyy suoraan PC1640:een.

---

## Lähteet

- [Amstrad PC1640 Technical Reference Manual](https://www.seasip.info/AmstradXT/1640tech/section1.html)
- [Amstrad PC1512 Technical Reference Manual](https://www.seasip.info/AmstradXT/1512tech/section1.html)
- [PC1640 DIP Switch Settings](https://www.seasip.info/AmstradXT/pc1640dip.html)
- [Amstrad PC1640 Revival (RetroNerd)](https://retronerd.co.uk/amstrad-pc1640-revival/)
- [PC1512 Video Inverter Circuit (ctrl-alt-rees)](https://ctrl-alt-rees.com/2018-09-25-amstrad-pc1512-video-inverter-circuit.html)
- [Amstrad PC1640 Service Manual (PDF)](https://www.minuszerodegrees.net/manuals/Amstrad/Amstrad_PC1640_PC-MD_PC-CD_PC-ECD_Service_Manual_300dpi_Agujereado.pdf)
- [Amstrad PC1512 PC-MM Service Manual (Internet Archive)](https://archive.org/details/amstrad-pc1512-pc-mm-pc-cm-service-manual)
- [IBM MDA/CGA/EGA Pinouts](https://www.minuszerodegrees.net/mda_cga_ega/mda_cga_ega.htm)

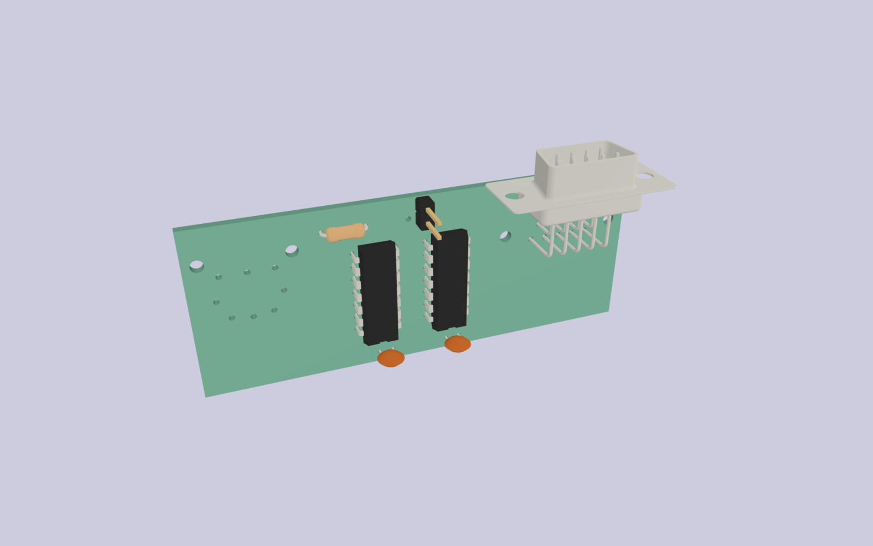
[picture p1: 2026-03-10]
hardware/pcb-3d-render.png

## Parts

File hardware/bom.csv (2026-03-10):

Reference | Value | Footprint | Quantity | Description | Supplier | Notes
U1 | 74HC04 | Package_DIP:DIP-14_W7.62mm | 1 | Hex inverter | Mouser: 595-SN74HC04N, Digikey: 296-1566-5-ND | 5 of 6 gates used
U2 | 74HC86 | Package_DIP:DIP-14_W7.62mm | 1 | Quad 2-input XOR gate | Mouser: 595-SN74HC86N, Digikey: 296-1606-5-ND | 1 of 4 gates used
C1 | 100nF | Capacitor_THT:C_Disc_D5.0mm_W2.5mm_P2.50mm | 1 | Ceramic decoupling cap for U1 |  | Place close to U1 VCC/GND
C2 | 100nF | Capacitor_THT:C_Disc_D5.0mm_W2.5mm_P2.50mm | 1 | Ceramic decoupling cap for U2 |  | Place close to U2 VCC/GND
R1 | 10k | Resistor_THT:R_Axial_DIN0207_L6.3mm_D2.5mm_P7.62mm | 1 | Pull-up for DIN pin 4 (Black) to VCC |  | 1/4W
J1 | DB9_Male | Connector_Dsub:DSUB-9_Male_Horizontal_P2.77x2.84mm | 1 | DE-9 male right-angle PCB mount |  | Plugs into PC1640 video output
J2 | DIN-8 | Connector_DIN:DIN-8_Mini | 1 | 8-pin DIN female PCB mount |  | PC-MM video cable plugs into this
J3 | Conn_01x02 | Connector_PinHeader_2.54mm:PinHeader_1x02_P2.54mm | 1 | Power input header +5V/GND |  | Or USB Micro-B breakout board

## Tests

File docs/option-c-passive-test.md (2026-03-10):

# Vaihtoehto C: Passiivinen adapteri ilman IC:tä (testaustarkoituksiin)

Nopea ja halpa testi ennen varsinaisen adapterin rakentamista. Ei vaadi IC-hankintoja.

## Toimintaperiaate

- R, G, B, I kytketään suoraan ilman inversiota
- H-Sync ja V-Sync yhdistetään vastusverkolla (epätarkempi kuin XOR, mutta voi riittää)
- **Kuva on negatiivi** (valkoinen teksti → musta, musta tausta → valkoinen) koska PC-MM:n sisäinen invertteri kääntää signaalit väärinpäin

## Kytkentä

```
PC1640 (DE-9)                                    PC-MM (8-pin DIN)
═════════════                                    ═════════════════

Pin 3 (R)  ─────────── suora ─────────────────→  Pin 8 (Red)
Pin 4 (G)  ─────────── suora ─────────────────→  Pin 5 (Green)
Pin 5 (B)  ─────────── suora ─────────────────→  Pin 6 (Blue)
Pin 6 (I)  ─────────── suora ─────────────────→  Pin 2 (Intensity)

Pin 8 (H-Sync) ──── 1kΩ ──→┐
                             ├──────────────→  Pin 1 (C-Sync)
Pin 9 (V-Sync) ──── 1kΩ ──→┘

Pin 1 (GND) ──────────── GND ────────────────→  Pin 3, Pin 7 (GND)
                                                 Pin 4 (Black) ← irti
```

## Tarvikkeet

| Komponentti | Arvo | Kpl | Hinta  |
|---|---|-----|---|
| Vastus | 1kΩ | 2 | ~0,10€ |
| DE-9 uros (tai liitin) | — | 1 | ~1,50€ |
| 8-pin DIN naaras (tai kaapeli) | — | 1 | ~2,00€ |
| Protolevy / juotoslanka  | — | 1 | ~1,00€ |
| | | | **~5€**|

## Mitä odottaa

### Kuva näkyy mutta on negatiivi
Tämä tarkoittaa, että signaalireitti toimii mutta inversio puuttuu. **Hyvä merkki** — siirry vaihtoehtoon A.

### Kuva rullaa pystysuunnassa
Composite sync ei toimi oikein vastusverkolla. Kokeile eri vastusarvoja (470Ω–2,2kΩ) tai siirry XOR-piiriin (vaihtoehto A/B).

### Ei kuvaa ollenkaan
Tarkista:
- Onko PC1640 CGA-tilassa (SW8 = OFF)?
- Ovatko GND-yhteydet kunnossa?
- Ovatko pinnit oikein (mittaa jännitteet)?

### Kuva on oikein päin
Epätodennäköistä, mutta jos näin käy, PC-MM:n sisäinen invertteri käyttäytyy eri tavalla kuin dokumentoitu. Hyvä uutinen — suora adapteri ilman invertteriä riittää.

## Rajoitukset

- **Ei tuotantokäyttöön** — vastusverkko-sync on epäluotettava
- Kuva on käänteinen — käytettävyys on heikko
- Vastusverkon impedanssi voi aiheuttaa häiriöitä kuvassa

## Tarkoitus

Tämä vaihtoehto on tarkoitettu **ainoastaan** ensimmäiseksi testiksi, jolla varmistetaan:
1. PC1640:n CGA-tilan taajuus on yhteensopiva PC-MM:n kanssa
2. Signaalireitti DE-9 → DIN toimii fyysisesti
3. Monitori syttyy ja näyttää jotain

Tulosten perusteella päätetään jatketaanko vaihtoehdolla A vai B.

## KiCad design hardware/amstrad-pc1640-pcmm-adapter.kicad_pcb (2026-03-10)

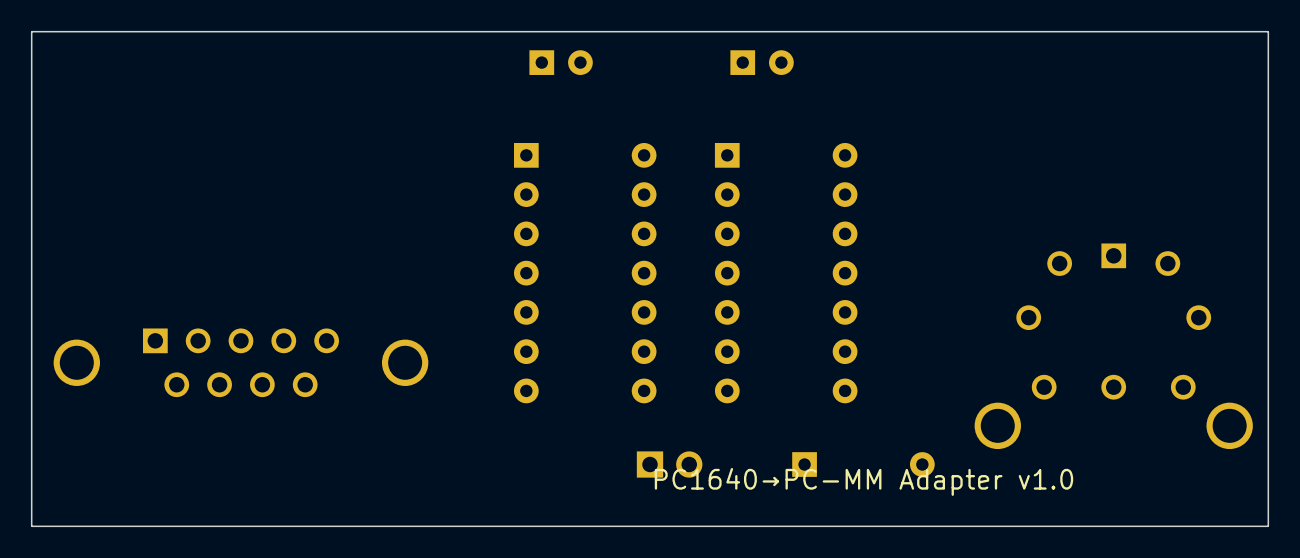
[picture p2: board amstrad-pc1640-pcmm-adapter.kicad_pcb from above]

Board: 2 copper layers, 80.0 x 32.0 mm, 8 parts (0 on the bottom side), 15 nets, no tracks yet.

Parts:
C1, C2: 100nF; C_Disc_D5.0mm_W2.5mm_P2.50mm
J1: DB9_Male; DSUB-9_Male_Horizontal_P2.77x2.84mm
J2: DIN-8; DIN-8_Video
J3: +5V/GND; PinHeader_1x02_P2.54mm_Vertical
R1: 10k; R_Axial_DIN0207_L6.3mm_D2.5mm_P7.62mm_Horizontal
U1: 74HC04; DIP-14_W7.62mm
U2: 74HC86; DIP-14_W7.62mm

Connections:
+5V: C1.1, C2.1, J3.1, R1.1, U1.14, U2.14
BLACK: J2.4, R1.2
BLUE: J1.5, U1.5
BLUE_INV: J2.6, U1.6
CSYNC: U1.11, U2.3
CSYNC_INV: J2.1, U1.10
GND: C1.2, C2.2, J1.1, J2.3, J2.7, J2.SH1, J2.SH2, J3.2, U1.7, U1.13, U2.4, U2.5, U2.7, U2.9, U2.10, U2.12, U2.13
GREEN: J1.4, U1.3
GREEN_INV: J2.5, U1.4
HSYNC: J1.8, U2.1
INTENSITY: J1.6, U1.9
INTENSITY_INV: J2.2, U1.8
RED: J1.3, U1.1
RED_INV: J2.8, U1.2
VSYNC: J1.9, U2.2

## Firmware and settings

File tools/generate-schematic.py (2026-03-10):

#!/usr/bin/env python3
"""
Generoi KiCad-skeema (.kicad_sch) Amstrad PC1640→PC-MM adapterille.

Komponentit:
  U1: 74HC04 hex inverter (DIP-14)
  U2: 74HC86 quad XOR (DIP-14)
  C1, C2: 100nF decoupling
  R1: 10kΩ pull-up
  J1: DE-9 Male (PC1640)
  J2: DIN-8 Female (PC-MM)
  J3: 2-pin power header
"""
import uuid

SCH_UUID = "e63e39d7-6ac0-4ffd-8aa3-1841a4541b55"


def uid():
    return str(uuid.uuid4())


def pin_def(name, number, x, y, direction, pin_type="bidirectional"):
    return f"""        (pin {pin_type} line
          (at {x} {y} {direction})
          (length 2.54)
          (name "{name}" (effects (font (size 1.27 1.27))))
          (number "{number}" (effects (font (size 1.27 1.27))))
        )"""


def sym_74hc04():
    """74HC04 hex inverter symbol - simplified as DIP-14 box."""
    pins = []
    # Left side: pins 1-7 (top to bottom)
    left_names = ["1A", "1Y", "2A", "2Y", "3A", "3Y", "GND"]
    for i, name in enumerate(left_names):
        pt = "passive" if name == "GND" else "bidirectional"
        pins.append(pin_def(name, str(i+1), -15.24, 15.24 - i*5.08, 0, pt))
    # Right side: pins 14-8 (top to bottom)
    right_names = ["VCC", "6A", "6Y", "5A", "5Y", "4A", "4Y"]
    right_nums = [14, 13, 12, 11, 10, 9, 8]
    for i, (name, num) in enumerate(zip(right_names, right_nums)):
        pt = "power_in" if name == "VCC" else "bidirectional"
        pins.append(pin_def(name, str(num), 15.24, 15.24 - i*5.08, 180, pt))

    return f"""    (symbol "adapter:74HC04"
      (in_bom yes) (on_board yes)
      (property "Reference" "U" (at 0 20.32 0)
        (effects (font (size 1.27 1.27))))
      (property "Value" "74HC04" (at 0 -20.32 0)
        (effects (font (size 1.27 1.27))))
      (property "Footprint" "Package_DIP:DIP-14_W7.62mm" (at 0 -22.86 0)
        (effects (font (size 1.27 1.27)) hide))
      (symbol "74HC04_0_1"
        (rectangle (start -12.7 19.05) (end 12.7 -19.05)
          (stroke (width 0.254) (type default))
          (fill (type background))))
      (symbol "74HC04_1_1"
{chr(10).join(pins)}
      )
    )"""


def sym_74hc86():
    """74HC86 quad XOR symbol - simplified as DIP-14 box."""
    pins = []
    left_names = ["1A", "1B", "1Y", "2A", "2B", "2Y", "GND"]
    for i, name in enumerate(left_names):
        pt = "passive" if name == "GND" else "bidirectional"
        pins.append(pin_def(name, str(i+1), -15.24, 15.24 - i*5.08, 0, pt))
    right_names = ["VCC", "4B", "4A", "4Y", "3Y", "3B", "3A"]
    right_nums = [14, 13, 12, 11, 10, 9, 8]
    for i, (name, num) in enumerate(zip(right_names, right_nums)):
        pt = "power_in" if name == "VCC" else "bidirectional"
        pins.append(pin_def(name, str(num), 15.24, 15.24 - i*5.08, 180, pt))

    return f"""    (symbol "adapter:74HC86"
      (in_bom yes) (on_board yes)
      (property "Reference" "U" (at 0 20.32 0)
        (effects (font (size 1.27 1.27))))
      (property "Value" "74HC86" (at 0 -20.32 0)
        (effects (font (size 1.27 1.27))))
      (property "Footprint" "Package_DIP:DIP-14_W7.62mm" (at 0 -22.86 0)
        (effects (font (size 1.27 1.27)) hide))
      (symbol "74HC86_0_1"
        (rectangle (start -12.7 19.05) (end 12.7 -19.05)
          (stroke (width 0.254) (type default))
          (fill (type background))))
      (symbol "74HC86_1_1"
{chr(10).join(pins)}
      )
    )"""


def sym_connector(name, ref_prefix, pin_count, pin_names, footprint):
    """Generic connector symbol."""
    pins = []
    half = pin_count * 5.08 / 2
    for i, pname in enumerate(pin_names):
        pins.append(pin_def(pname, str(i+1), -15.24, half - i*5.08 - 2.54, 0, "passive"))

    return f"""    (symbol "adapter:{name}"
      (in_bom yes) (on_board yes)
      (property "Reference" "{ref_prefix}" (at 0 {half + 2.54} 0)
        (effects (font (size 1.27 1.27))))
      (property "Value" "{name}" (at 0 {-half - 2.54} 0)
        (effects (font (size 1.27 1.27))))
      (property "Footprint" "{footprint}" (at 0 {-half - 5.08} 0)
        (effects (font (size 1.27 1.27)) hide))
      (symbol "{name}_0_1"
        (rectangle (start -12.7 {half + 1.27}) (end 12.7 {-half - 1.27})
          (stroke (width 0.254) (type default))
          (fill (type background))))
      (symbol "{name}_1_1"
{chr(10).join(pins)}
      )
    )"""


def sym_passive(name, ref_prefix, footprint):
    """Resistor or capacitor symbol (2-pin)."""
    return f"""    (symbol "adapter:{name}"
      (in_bom yes) (on_board yes)
      (property "Reference" "{ref_prefix}" (at 0 2.54 0)
        (effects (font (size 1.27 1.27))))
      (property "Value" "{name}" (at 0 -2.54 0)
        (effects (font (size 1.27 1.27))))
      (property "Footprint" "{footprint}" (at 0 -5.08 0)
        (effects (font (size 1.27 1.27)) hide))
      (symbol "{name}_0_1"
        (rectangle (start -2.54 1.27) (end 2.54 -1.27)
          (stroke (width 0.254) (type default))
          (fill (type background))))
      (symbol "{name}_1_1"
        (pin passive line (at -5.08 0 0) (length 2.54)
          (name "1" (effects (font (size 1.27 1.27))))
          (number "1" (effects (font (size 1.27 1.27)))))
        (pin passive line (at 5.08 0 180) (length 2.54)
          (name "2" (effects (font (size 1.27 1.27))))
          (number "2" (effects (font (size 1.27 1.27)))))
      )
    )"""


def sym_power(name, number):
    """Power symbol (+5V or GND)."""
    return f"""    (symbol "power:{name}"
      (power)
      (in_bom yes) (on_board yes)
      (property "Reference" "#{name}" (at 0 2.54 0)
        (effects (font (size 1.27 1.27)) hide))
      (property "Value" "{name}" (at 0 3.81 0)
        (effects (font (size 1.0 1.0))))
      (symbol "{name}_0_1"
        (polyline (pts (xy 0 0) (xy 0 1.27))
          (stroke (width 0) (type default))
          (fill (type none))))
      (symbol "{name}_1_1"
        (pin power_in line (at 0 0 90) (length 0) (hide yes)
          (name "{name}" (effects (font (size 1.27 1.27))))
          (number "{number}" (effects (font (size 1.27 1.27)))))
      )
    )"""


def symbol_instance(lib_name, ref, value, x, y, unit=1):
    """Place a symbol instance on the schematic."""
    return f"""  (symbol
    (lib_id "adapter:{lib_name}")
    (at {x} {y} 0)
    (unit {unit})
    (exclude_from_sim no)
    (in_bom yes)
    (on_board yes)
    (dnp no)
    (uuid "{uid()}")
    (property "Reference" "{ref}" (at 0 -22.86 0)
      (effects (font (size 1.27 1.27))))
    (property "Value" "{value}" (at 0 -25.40 0)
      (effects (font (size 1.27 1.27))))
  )"""


def power_instance(name, x, y, rot=90):
    """Place a power symbol."""
    return f"""  (symbol
    (lib_id "power:{name}")
    (at {x} {y} {rot})
    (unit 1)
    (exclude_from_sim no)
    (in_bom yes)
    (on_board yes)
    (dnp no)
    (uuid "{uid()}")
    (property "Reference" "#{name}" (at 0 0 0)
      (effects (font (size 1.27 1.27)) hide))
    (property "Value" "{name}" (at 3.81 0 0)
      (effects (font (size 1.0 1.0))))
  )"""
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

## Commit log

2026-03-10 Initial commit: Amstrad PC1640 to PC-MM monitor adapter documentation
    Signal analysis, pinouts, and three adapter design options for connecting
    an Amstrad PC1640 (EGA/CGA, DE-9) to an Amstrad PC-MM monochrome monitor
    (inverted RGBI, 8-pin DIN, composite sync).
2026-03-10 Add Option D: EGA mode adapter with scan rate conversion analysis
    New option for keeping PC1640 in EGA mode (SW8=ON). Covers two tiers:
    - D1: 200-line programs with EGA 6-bit to CGA RGBI conversion (diode-OR)
    - D2: 350-line programs requiring external scan rate converter (MCE2VGA,
    GBS-Control, OSSC Pro)
    Includes software compatibility list and cost analysis for all approaches.
2026-03-10 Add hardware files for Option A: KiCad project, BOM, and netlist
    Selected Option A (external adapter, 74HC04 + 74HC86) as the build target.
    - KiCad project file ready to open and draw schematic
    - BOM with Mouser/Digikey part numbers for all components
    - Complete point-to-point netlist with ASCII wiring diagram
    [bom.csv]
2026-03-10 Add KiCad schematic, PCB layout, and validation pipeline
    Generated files:
    - KiCad schematic (.kicad_sch) with all components and net labels
    - KiCad PCB layout (.kicad_pcb) 80x45mm 2-layer with validated placement
    Validation tools (adapted from 64korppu process):
    - generate-pcb.py: generates PCB with optimized component placement
    - generate-schematic.py: generates schematic with symbol definitions
    - pcb-validate.py: pre-routing checks (boundaries, overlaps, collisions)
    - pcb-drc-check.py: post-routing DRC analysis with severity classification
    - pcb-pipeline.sh: full pipeline (validate → route → DRC → gerbers)
    All pre-routing validations pass: 0 boundary errors, 0 pad overlaps,
    0 body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
    [amstrad-pc1640-pcmm-adapter.kicad_pcb, amstrad-pc1640-pcmm-adapter.kicad_sch]
2026-03-10 Complete PCB routing and generate manufacturing files
    Freerouting auto-routed all nets in 5 passes (0.85s), 0 unrouted.
    DRC passed: 0 critical errors, 0 unconnected items, 1 cosmetic warning.
    Generated outputs:
    - Routed PCB with GND copper pour on B.Cu
    - Gerber files (F.Cu, B.Cu, silkscreen, mask, edge cuts, drill)
    - Manufacturing-ready zip for JLCPCB/PCBWay
    - GenCAD export for BOM tools
    - Specctra DSN/SES files
    [amstrad-pc1640-pcmm-adapter-B_Cu.gbl, amstrad-pc1640-pcmm-adapter-B_Mask.gbs, amstrad-pc1640-pcmm-adapter-B_Silkscreen.gbo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]
2026-03-10 Reduce PCB from 80x45mm to 80x32mm by moving J3 and R1 up
    Moved J3 (+5V/GND header) from y=121 to y=108 (below ICs) and
    R1 from (157,112) to (150,108). Board height reduced 29%.
    All nets routed, DRC passed.
    [amstrad-pc1640-pcmm-adapter-B_Cu.gbl, amstrad-pc1640-pcmm-adapter-B_Mask.gbs, amstrad-pc1640-pcmm-adapter-B_Silkscreen.gbo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]
2026-03-10 Add 3D model references and render PCB with components
    Added 3D model paths (DIP-14, DE-9, capacitors, resistor, pin header)
    to generate-pcb.py footprints. Rendered via GLB export + pyrender since
    kicad-cli render doesn't load 3D models on macOS. DIN-8 connector has
    no standard KiCad 3D model.
    [amstrad-pc1640-pcmm-adapter-B_Cu.gbl, amstrad-pc1640-pcmm-adapter-B_Mask.gbs, amstrad-pc1640-pcmm-adapter-B_Silkscreen.gbo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]
2026-10-21 fix: keep PCB pipeline filenames out of Python source (#1)
